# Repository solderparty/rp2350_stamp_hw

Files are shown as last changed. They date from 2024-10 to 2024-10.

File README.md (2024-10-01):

# The RP2350 Stamp

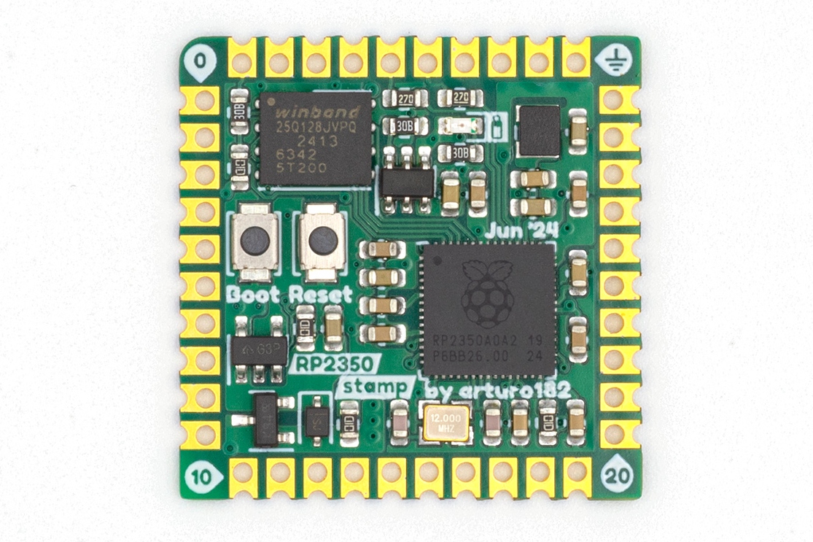
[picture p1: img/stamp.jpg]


The Stamp was created to allow you to use the **Raspberry Pi RP2350A** in your designs without having to solder small-pitch QFN chips or worry about lots of external circuitry.

The RP2350 Stamp is pad-compatible with our previous RP2040 Stamp.

All you need to get you started is a 5V supply or a LiPo battery. The Stamp will take care of the charging and switching the power sources.

The castellated edges with **2mm pitch** can be hand-soldered directly to a Carrier board, used with pin headers for more flexibility, or connected without soldering using [FlexyPins](https://flexypin.solder.party), which are spring connectors designed for modules with castellated edges. You can find footprints for many PCB programs [here](https://github.com/solderparty/rp2xxx_stamp_footprints).

At only **1 by 1 inch**, the Stamp packs a lot of features:
* **16MB of FLASH**
* **500mA 3.3V LDO**
* **All 30 GPIOs broken out**
* LiPo supply and charging circuit (with charging LED)
* USB broken out
* SWD broken out
* Reset Button
* Bootsel Button
* 12MHz crystal

and of course, everything that comes with the Raspberry Pi RP2350 itself:
* Dual core ARM Cortex-M33 or Hazard3 @ 150MHz
* 520kB SRAM
* 2 UARTs
* 2 SPIs
* 2 I2Cs
* 24 PWM channels
* 12 PIO state machines
* 1 HSTX peripheral
* USB with Host and Device support

The RP2350 comes with a pre-programmed ROM UF2 Bootloader, by pulling the BOOTSEL pin low and resetting, or by double-pressing the RESET button (if the FW supports it), you can upload new firmware using the USB disk drive.

In addition to the Stamps we also offer a few reference designs, see the Carriers in the [Stamp-related category](https://docs.solder.party/rp2xxx-stamp-related) as well as our [Flux projects](https://docs.solder.party/flux).

The CircuitPython firmware for the Stamp comes with a built-in board files for the Carriers, for example you can access the RP2040 Stamp Carrier pins and interfaces by using `import stamp_carrier_board as board`. See [here](https://github.com/adafruit/circuitpython/tree/main/ports/raspberrypi/boards/solderparty_rp2040_stamp) for all the available Carrier board files.

# Links

For more information visit https://rp2350-stamp.solder.party/

Buy it on Lectronz (https://lectronz.com/products/rp2350-stamp)

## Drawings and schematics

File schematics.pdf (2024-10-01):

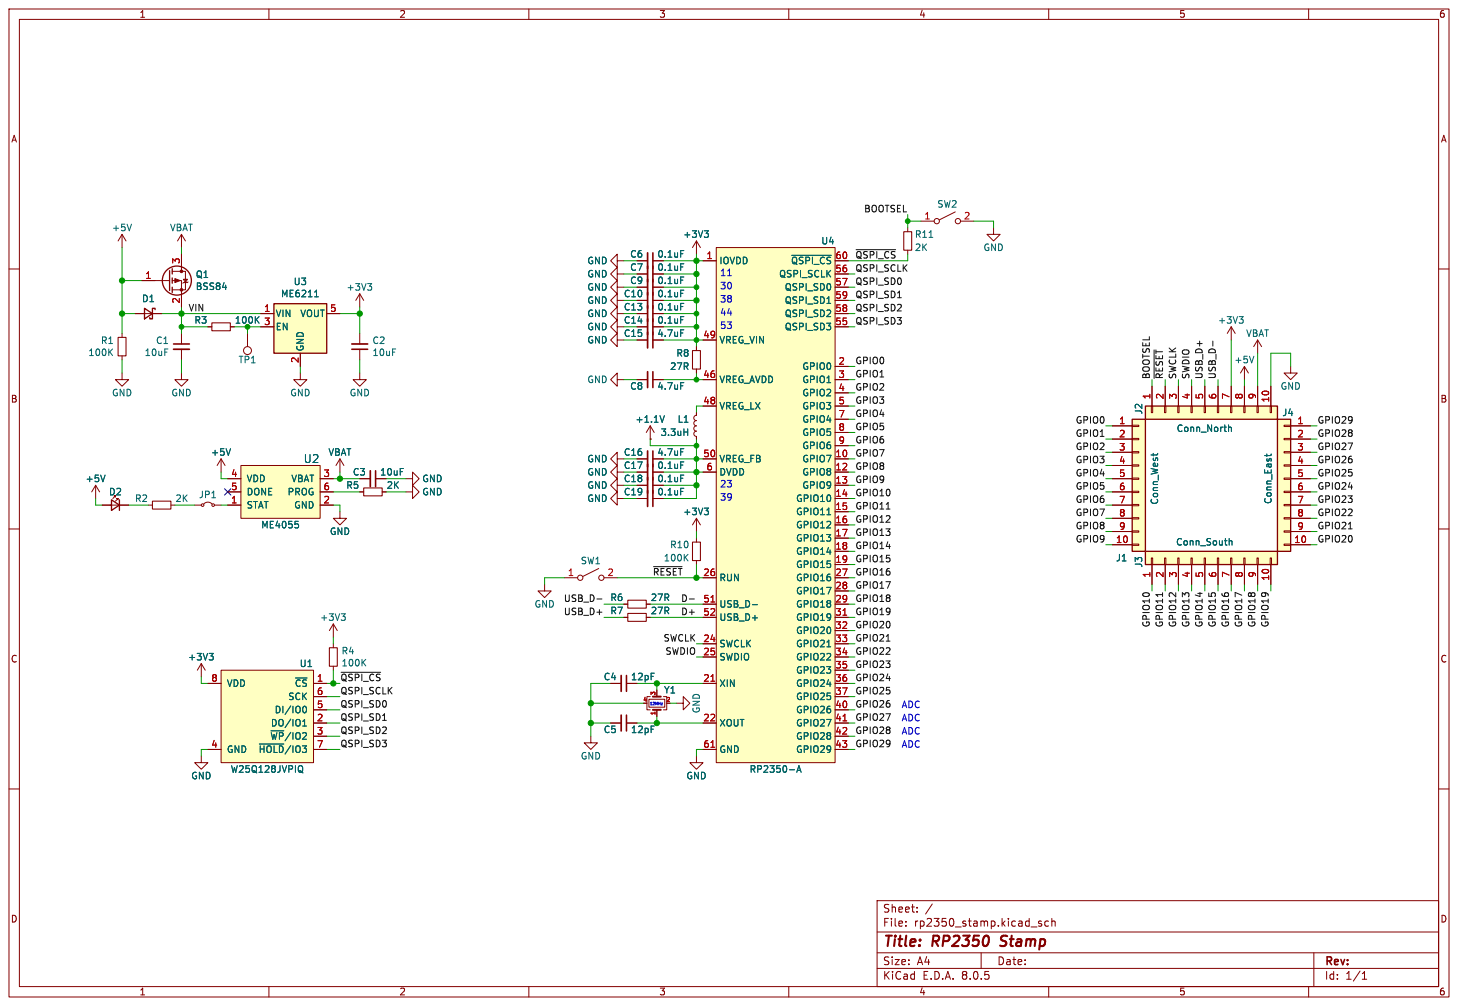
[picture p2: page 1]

+3V3 GND GND GND GND GND GND GND
+5V GND GND GND GND

2 EN 3 VOUT 5 R5 2K GND GND C3 10uF U2 ME4055 STAT 1 GND 2 VBAT 3 VDD 4 DONE 5 PROG 6GND

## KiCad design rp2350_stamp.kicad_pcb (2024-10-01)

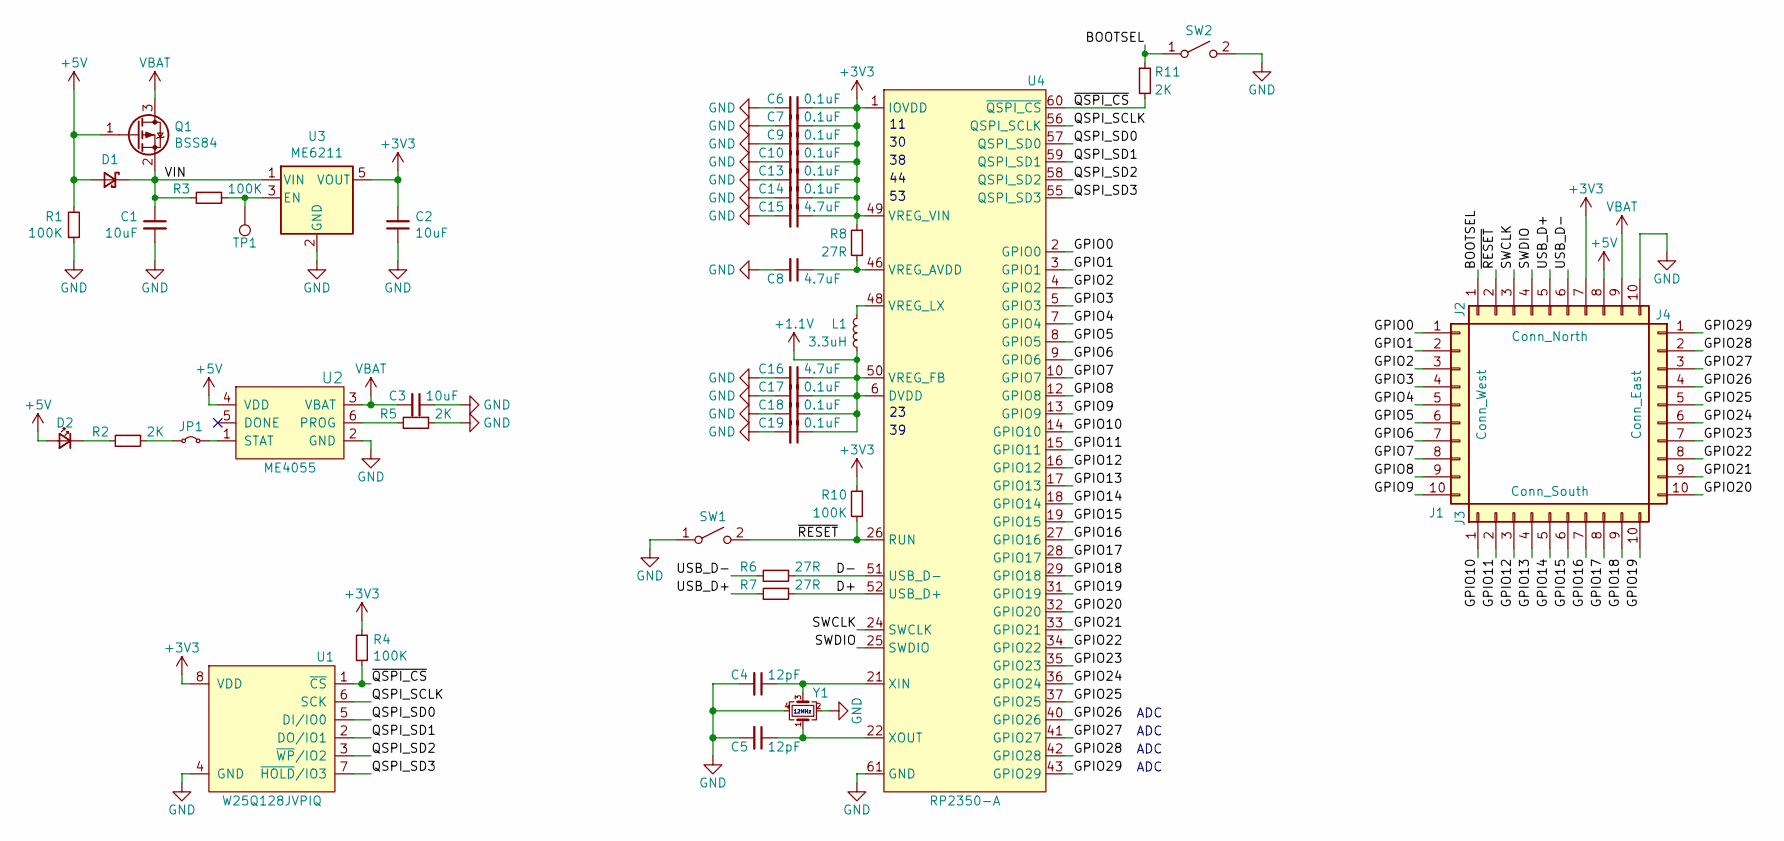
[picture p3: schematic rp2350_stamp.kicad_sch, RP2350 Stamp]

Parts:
C1, C2, C3: 10uF; C_0603_1608Metric
C4, C5: 12pF; C_0603_1608Metric
C6, C7, C9, C10, C13, C14, C17, C18, C19: 0.1uF; C_0603_1608Metric
C8, C15, C16: 4.7uF; C_0603_1608Metric
D1: D_Schottky_Small; D_SOD-323; LCSC C114023
D2: LED_CHR; LED_0603_1608Metric
J1: Conn_West; Castellated_1x10_P2.00mm_Vertical
J2: Conn_North; Castellated_1x10_P2.00mm_Vertical
J3: Conn_South; Castellated_1x10_P2.00mm_Vertical
J4: Conn_East; Castellated_1x10_P2.00mm_Vertical
JP1: SJ_STAT_LED; SolderJumper-2_P1.3mm_Bridged_RoundedPad1.0x1.5mm
L1: 3.3uH; L_Wuerth_MAPI-2512; LCSC C5832359
Q1: BSS84; SOT-23; LCSC C85202
R1, R3, R4, R10: 100K; R_0603_1608Metric
R2, R5, R11: 2K; R_0603_1608Metric
R6, R7, R8: 27R; R_0603_1608Metric
SW1: SW_RESET; SW_SPST_B3U-1000P; LCSC C561514
SW2: SW_BOOTSEL; SW_SPST_B3U-1000P; LCSC C561514
TP1: TP_LDO_EN; TestPoint_Pad_D1.5mm
U1: W25Q128JVPIQ; WSON-8-1EP_6x5mm_P1.27mm_EP3.4x4mm; LCSC C190862
U2: ME4055; SOT-23-6; LCSC C82121
U3: ME6211; SOT-23-5; LCSC C82942
U4: RP2350-A; QFN-60_EP_7x7_Pitch0.4mm
Y1: CM4012M00012001; Crystal_SMD_2520-4Pin_2.5x2.0mm; LCSC C7294611

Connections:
+1.1V: C16.1, C17.1, C18.1, C19.1, L1.1, U4.6 (DVDD), U4.23 (DVDD), U4.39 (DVDD), U4.50 (VREG_FB)
+3V3: C2.2, C6.1, C7.1, C9.1, C10.1, C13.1, C14.1, C15.1, J2.7, R4.2, R8.1, R10.1, U1.8 (VDD), U3.5 (VOUT), U4.1 (IOVDD), U4.11 (IOVDD), U4.20 (IOVDD), U4.30 (IOVDD), U4.38 (IOVDD), U4.44 (IOVDD), U4.45 (IOVDD), U4.49 (VREG_VIN), U4.53 (IOVDD), U4.54 (IOVDD)
+5V: D1.2 (A), D2.2 (A), J2.8, Q1.1 (G), R1.2, U2.4 (VDD)
/BOOTSEL: J2.1, R11.1, SW2.1 (A)
/D+: R7.1, U4.52 (USB_D+)
/D-: R6.1, U4.51 (USB_D-)
/GPIO0: J1.1, U4.2 (GPIO0)
/GPIO1: J1.2, U4.3 (GPIO1)
/GPIO2: J1.3, U4.4 (GPIO2)
/GPIO3: J1.4, U4.5 (GPIO3)
/GPIO4: J1.5, U4.7 (GPIO4)
/GPIO5: J1.6, U4.8 (GPIO5)
/GPIO6: J1.7, U4.9 (GPIO6)
/GPIO7: J1.8, U4.10 (GPIO7)
/GPIO8: J1.9, U4.12 (GPIO8)
/GPIO9: J1.10, U4.13 (GPIO9)
/GPIO10: J3.1, U4.14 (GPIO10)
/GPIO11: J3.2, U4.15 (GPIO11)
/GPIO12: J3.3, U4.16 (GPIO12)
/GPIO13: J3.4, U4.17 (GPIO13)
/GPIO14: J3.5, U4.18 (GPIO14)
/GPIO15: J3.6, U4.19 (GPIO15)
/GPIO16: J3.7, U4.27 (GPIO16)
/GPIO17: J3.8, U4.28 (GPIO17)
/GPIO18: J3.9, U4.29 (GPIO18)
/GPIO19: J3.10, U4.31 (GPIO19)
/GPIO20: J4.10, U4.32 (GPIO20)
/GPIO21: J4.9, U4.33 (GPIO21)
/GPIO22: J4.8, U4.34 (GPIO22)
/GPIO23: J4.7, U4.35 (GPIO23)
/GPIO24: J4.6, U4.36 (GPIO24)
/GPIO25: J4.5, U4.37 (GPIO25)
/GPIO26: J4.4, U4.40 (GPIO26)
/GPIO27: J4.3, U4.41 (GPIO27)
/GPIO28: J4.2, U4.42 (GPIO28)
/GPIO29: J4.1, U4.43 (GPIO29)
/QSPI_SCLK: U1.6 (SCK), U4.56 (QSPI_SCLK)
/QSPI_SD0: U1.5 (DI/IO0), U4.57 (QSPI_SD0)
/QSPI_SD1: U1.2 (DO/IO1), U4.59 (QSPI_SD1)
/QSPI_SD2: U1.3 (~WP/IO2), U4.58 (QSPI_SD2)
/QSPI_SD3: U1.7 (~HOLD/IO3), U4.55 (QSPI_SD3)
/SWCLK: J2.3, U4.24 (SWCLK)
/SWDIO: J2.4, U4.25 (SWDIO)
/USB_D+: J2.5, R7.2
/USB_D-: J2.6, R6.2
/VIN: C1.1, D1.1 (K), Q1.2 (S), R3.2, U3.1 (VIN)
/~QSPI_CS: R4.1, R11.2, U1.1 (~CS), U4.60 (~QSPI_CS)
/~RESET: J2.2, R10.2, SW1.2 (B), U4.26 (RUN)
GND: C1.2, C2.1, C3.1, C4.2, C5.2, C6.2, C7.2, C8.2, C9.2, C10.2, C13.2, C14.2, C15.2, C16.2, C17.2, C18.2, C19.2, J2.10, R1.1, R5.1, SW1.1 (A), SW2.2 (B), U1.4 (GND), U1.9 (GND), U2.2 (GND), U3.2 (GND), U4.47 (GND), U4.61 (GND), Y1.2, Y1.4
unnamed: D2.1 (K), R2.2
unnamed: JP1.1 (A), R2.1
unnamed: JP1.2 (B), U2.1 (STAT)
unnamed: R5.2, U2.6 (PROG)
unnamed: R3.1, TP1.1, U3.3 (EN)
unnamed: C8.1, R8.2, U4.46 (VREG_AVDD)
unnamed: L1.2, U4.48 (VREG_LX)
unnamed: C4.1, U4.21 (XIN), Y1.3
unnamed: C5.1, U4.22 (XOUT), Y1.1
VBAT: C3.2, J2.9, Q1.3 (D), U2.3 (VBAT)

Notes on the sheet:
ADC
12MHz

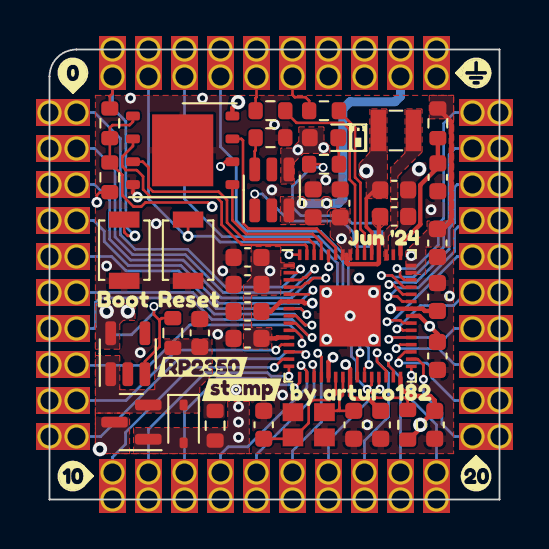
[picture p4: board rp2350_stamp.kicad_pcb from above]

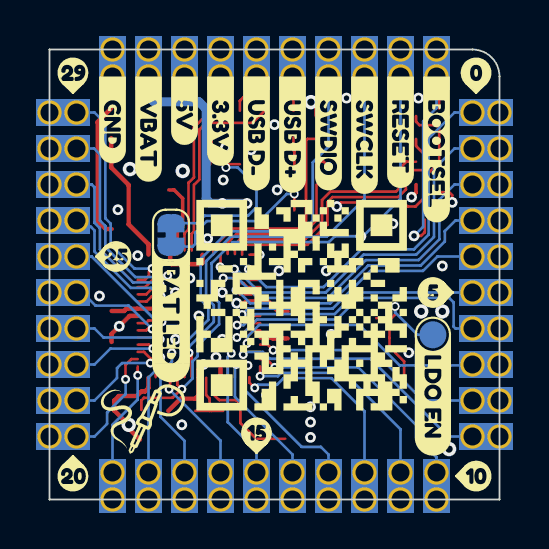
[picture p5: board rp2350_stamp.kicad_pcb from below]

Board: 4 copper layers, 25.0 x 25.0 mm, 74 parts (23 on the bottom side), 59 nets.

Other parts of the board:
kibuzzard-65C79539: G***; kibuzzard-65C79539
kibuzzard-6577C6A3: G***; kibuzzard-6577C6A3
kibuzzard-6577C69C: G***; kibuzzard-6577C69C
kibuzzard-6578FB5D: G***; kibuzzard-6578FB5D
kibuzzard-6578FB6C: G***; kibuzzard-6578FB6C
kibuzzard-6578FB20: G***; kibuzzard-6578FB20
kibuzzard-6578FB80: G***; kibuzzard-6578FB80
kibuzzard-6578FBA5: G***; kibuzzard-6578FBA5
kibuzzard-6578FBB3: G***; kibuzzard-6578FBB3
kibuzzard-6578FBCE: G***; kibuzzard-6578FBCE
kibuzzard-6578FC1D: G***; kibuzzard-6578FC1D
kibuzzard-6578FC06: G***; kibuzzard-6578FC06
kibuzzard-6578FC10: G***; kibuzzard-6578FC10
kibuzzard-6578FE34: G***; kibuzzard-6578FE34
kibuzzard-6605AA87: G***; kibuzzard-6605AA87
kibuzzard-6605AAE9: G***; kibuzzard-6605AAE9
kibuzzard-6605B0A1: G***; kibuzzard-6605B0A1
kibuzzard-6605B0D5: G***; kibuzzard-6605B0D5
kibuzzard-6695A5B8: G***; kibuzzard-6695A5B8
kibuzzard-6695A66B: G***; kibuzzard-6695A66B
kibuzzard-6695ACF2, kibuzzard-6695ACF2#2: G***; kibuzzard-6695ACF2
kibuzzard-6695AD2C, kibuzzard-6695AD2C#2: G***; kibuzzard-6695AD2C
kibuzzard-6695AD18, kibuzzard-6695AD18#2: G***; kibuzzard-6695AD18
kibuzzard-6695B1B2: G***; kibuzzard-6695B1B2
kibuzzard-6695B2B8: G***; kibuzzard-6695B2B8
kibuzzard-6695B237: G***; kibuzzard-6695B237
kibuzzard-6695B350: G***; kibuzzard-6695B350

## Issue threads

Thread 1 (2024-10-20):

High Clock Precision with TCXO

mungewell, 2024-10-20:
Can you please confirm what XTAL you are using on this board, and what it's stability over temp is?

I have a project which requires a very precise clock and, although I appreciate that not everyone wants to pay for the higher precision, there is a 'hack' which can place a TCXO on the same footprint as the normal XTAL for _just_ the cost of a couple of extra resistors....
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

Are you able to integrate this into your (future?) designs?

I am able to modify existing Pico boards, but looking for a design/supply with this already integrated.
https://github.com/mungewell/pico-timecode/issues/4#issuecomment-1950291082

arturo182, 2024-10-20:
Here's the datasheet of the XTAL used on the production units: https://www.lcsc.com/datasheet/lcsc_datasheet_2409292133_huaxindianzi-CM4012M00012001_C7294611.pdf

I think it's too late to modify this design and it is also quite space-limited for adding extra resistors, but I will consider if for future designs.

mungewell, 2024-10-20:
Understood, thanks.
+/-10PPM with no compensation is, lets say, 'budget optimized' ;-)

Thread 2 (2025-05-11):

How to burn the program

mayjack0312, 2025-05-11:
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

I am using a test board for testing, and the software is Arduino IDE; but the current situation is that the computer cannot recognize the development board port. What should I do?

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

arturo182, 2025-05-11:
I'm sorry, but the boards shown here are not official Solder Party products. For support, please contact the seller.

mayjack0312, 2025-05-12:
> I'm sorry, but the boards shown here are not official Solder Party products. For support, please contact the seller.

The baseboard uses https://github.com/solderparty/rp2xxx_stamp_carrier_xl_hw

I think the RP2350 Stamp in the picture above is the right choice.

Closed 2025-05-11.

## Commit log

2023-12-13 Rev 1
    [rp2350_stamp.kicad_pcb, rp2350_stamp.kicad_sch]
2024-02-11 Rev 2
    Swapped back to SOT-23 LiPo charger
    Added QR Code
    Added LDO EN back silk
    Moved around front silk
    [rp2350_stamp.kicad_pcb, rp2350_stamp.kicad_sch]
2024-03-28 Rev 3
    Added a solder jumper for BAT LED
    [rp2350_stamp.kicad_pcb, rp2350_stamp.kicad_sch]
2024-07-16 Rev 4
    - Put chip name on the board
    - Fixup pin markers to be uniform
    [rp2350_stamp.kicad_pcb, rp2350_stamp.kicad_sch]
2024-07-28 Rev 4.5
    Fixup power stuff according to RPi's recommendations
    [rp2350_stamp.kicad_pcb, rp2350_stamp.kicad_sch]
2024-10-01 Fix BOM info, add README and LICENSE
    [rp2350_stamp.kicad_pcb, rp2350_stamp.kicad_sch]
